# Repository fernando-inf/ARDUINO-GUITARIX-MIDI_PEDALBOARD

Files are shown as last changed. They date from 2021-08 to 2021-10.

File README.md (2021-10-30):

# FREE SOFTWARE - FREE WORLD - Try GNU / Linux is FREE.

https://www.gnu.org/

https://guitarix.org/

https://github.com/fernando-inf/ARDUINO-GUITARIX-MIDI_PEDALBOARD

# ARDUINO/GUITARIX- MIDI PEDALBOARD 
# (MIDI Input - MIDI Output)

- Licencia de uso: [GNU General Public License v3.0](https://github.com/fernando-inf/ARDUINO-GUITARIX-MIDI_PEDALBOARD/blob/main/LICENSE)
- English Version (Google translator): [ARDUINO/GUITARIX- MIDI PEDALBOARD](https://github-com.translate.goog/fernando-inf/ARDUINO-GUITARIX-MIDI_PEDALBOARD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,elem)
- Para reportar errores (Bugs) o solicitar ayuda [Registrarse en Github](https://github.com/signup?source=login) y dirijirse a la pestaña "Issues" que esta en la parte superior izquierda del repositorio.
- Para conocer a Guitarix mirar este video: [Tutorial Guitarix](https://youtu.be/nPbhc_3uhjE)

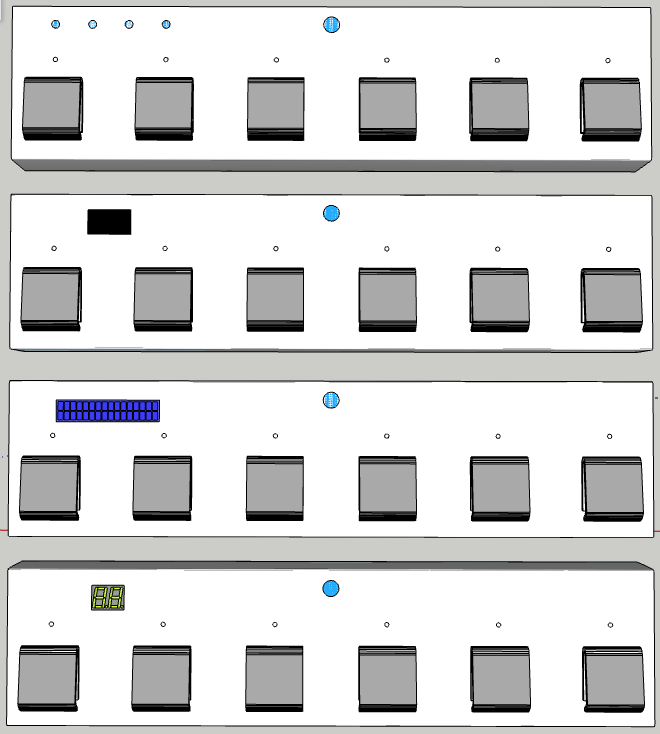
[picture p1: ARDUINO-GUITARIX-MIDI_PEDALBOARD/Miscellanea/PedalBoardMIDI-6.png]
 
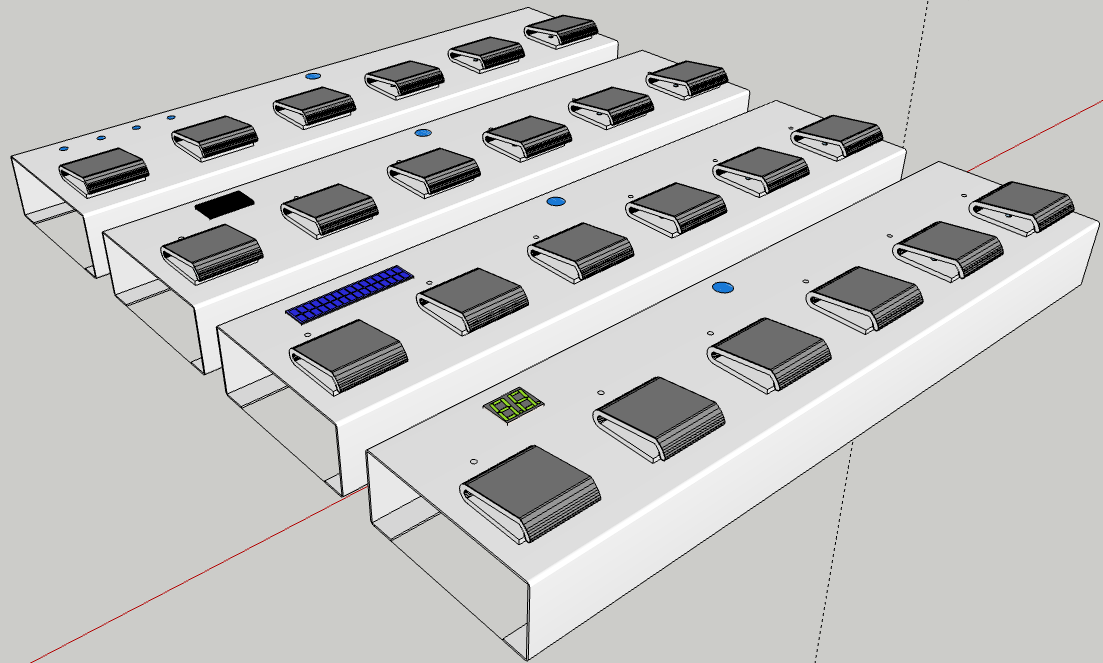
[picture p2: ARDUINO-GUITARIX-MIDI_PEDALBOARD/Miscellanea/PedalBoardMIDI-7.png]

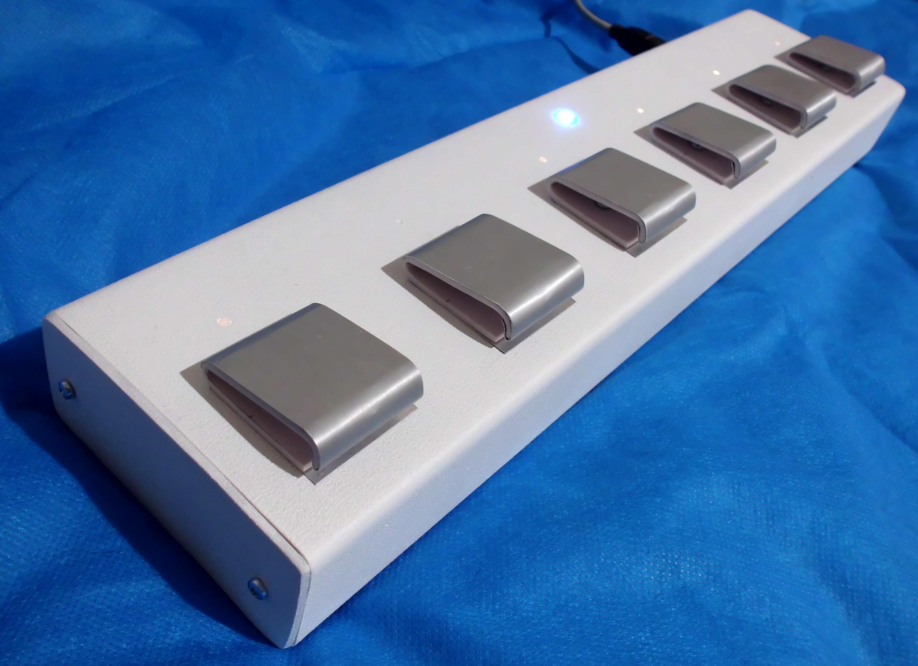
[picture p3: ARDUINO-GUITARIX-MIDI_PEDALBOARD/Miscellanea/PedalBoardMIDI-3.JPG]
 

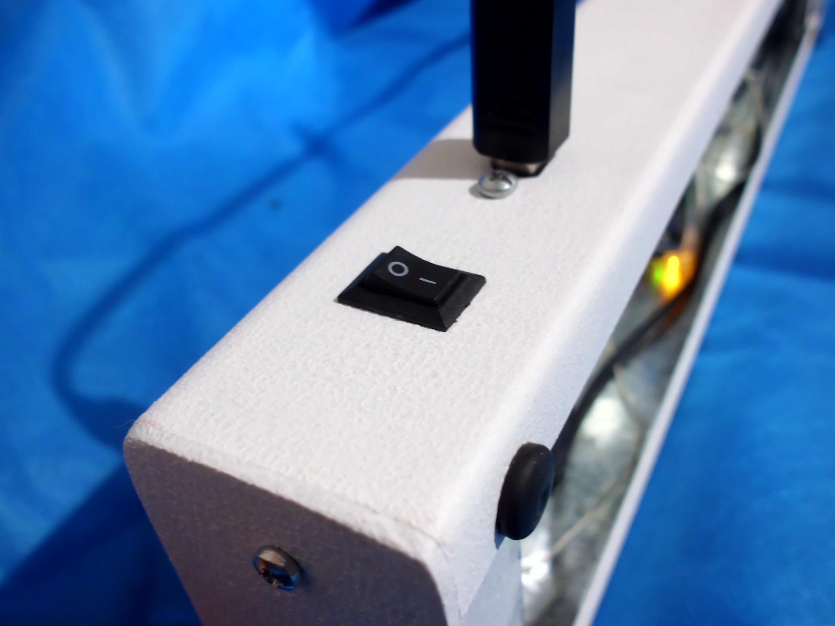
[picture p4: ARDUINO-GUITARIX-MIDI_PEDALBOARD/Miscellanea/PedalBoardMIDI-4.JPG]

 
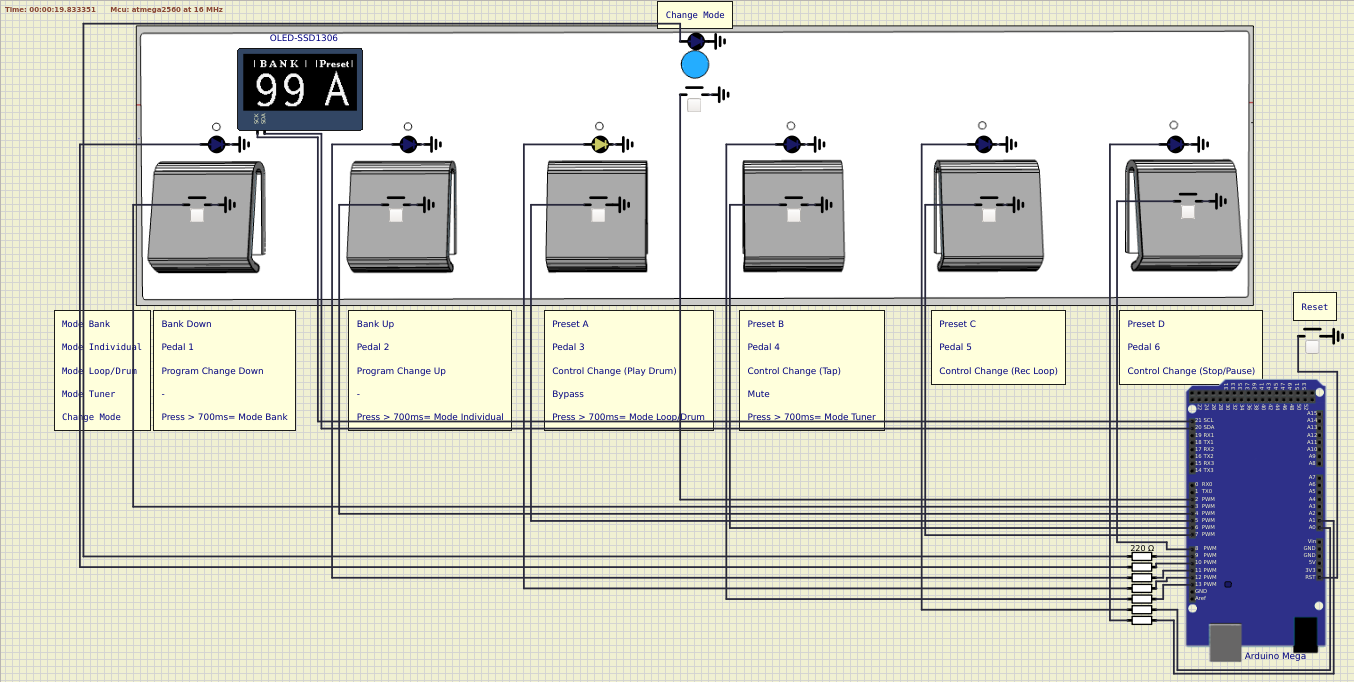
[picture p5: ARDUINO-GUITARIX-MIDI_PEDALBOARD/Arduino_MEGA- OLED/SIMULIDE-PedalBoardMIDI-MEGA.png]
 
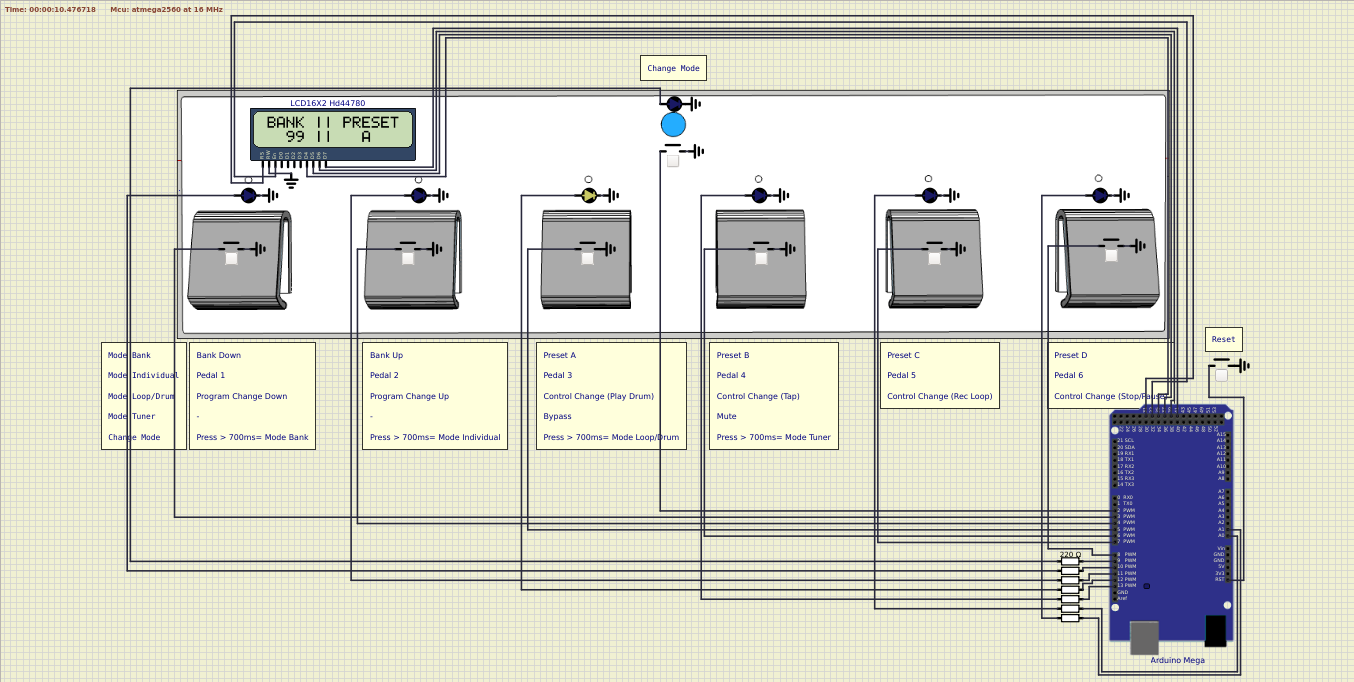
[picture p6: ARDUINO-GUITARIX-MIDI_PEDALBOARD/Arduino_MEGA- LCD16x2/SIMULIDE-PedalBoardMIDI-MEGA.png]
 
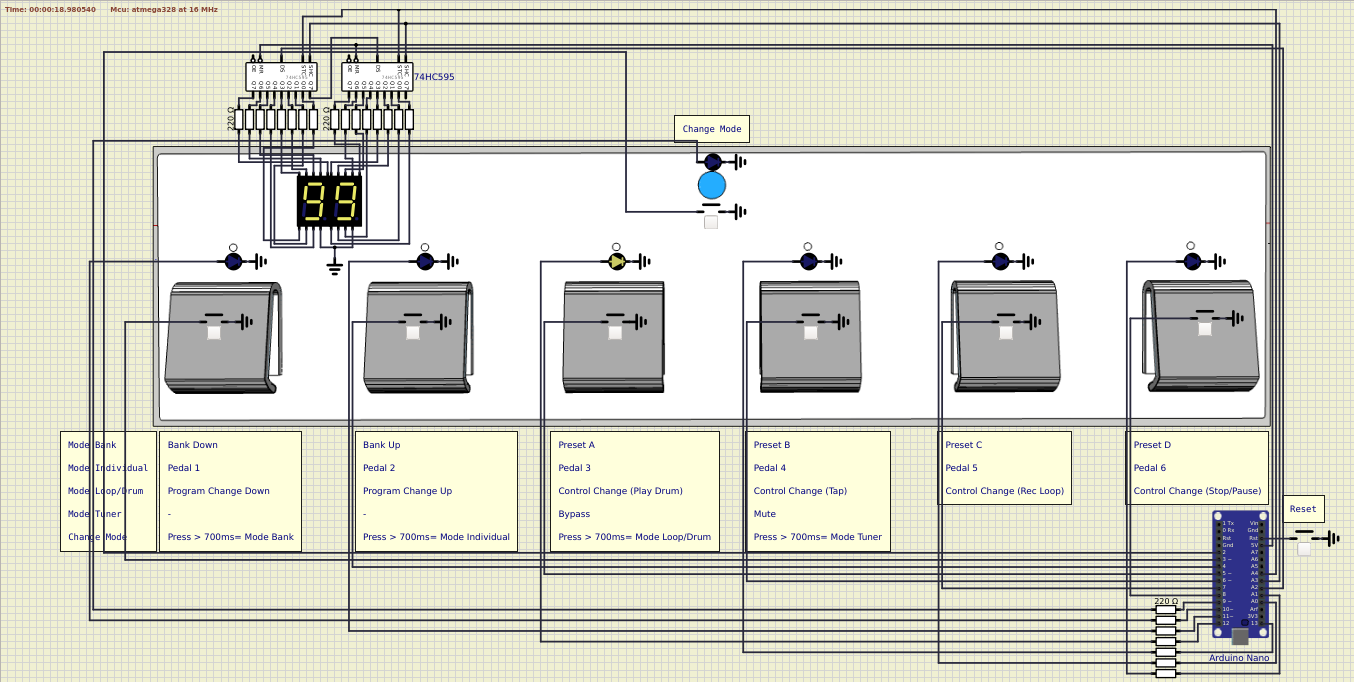
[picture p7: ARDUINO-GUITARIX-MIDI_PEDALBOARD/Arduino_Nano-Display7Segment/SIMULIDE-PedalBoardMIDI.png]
 
# INSTALACIÓN DEL FIRMWARE

- Abrir el archivo ARDUINO-GUITARIX-MIDI_PEDALBOARD.ino con Arduino IDE.

- Instále las dependencias:

  Previamente deberá tener instaladas estas librerías, para esto dirigirse a Arduino IDE "Herramientas ->   Administrar Bibliotecas..." y buscarlas:
  
  - [Bounce2](https://github.com/thomasfredericks/Bounce2)
  
  - [MIDI Library](https://github.com/FortySevenEffects/arduino_midi_library)
  
  - Si usa USB-MIDI: [Arudino USB-MIDI](https://github.com/lathoub/Arduino-USBMIDI)
  
  - Si usa Bluetooth con ESP32: 
  
      - [Pack de tarjetas adicionales ESP32](https://dl.espressif.com/dl/package_esp32_index.json)
                                
      - [Arduino BLE MIDI](https://github.com/lathoub/Arduino-BLE-MIDI)

  - Si usa LCD 16x2: [LiquidCrystal](https://www.arduino.cc/en/Reference/LiquidCrystal)
  
  - Si usa LCD 16x2 con I2C: [LiquidCrystal_I2C](https://github.com/johnrickman/LiquidCrystal_I2C)
  
  - Si usa OLED SSD1306 128x64 I2C: [U8g2](https://github.com/olikraus/u8g2)
  
- Habilíte su configuración con un valor = 1.

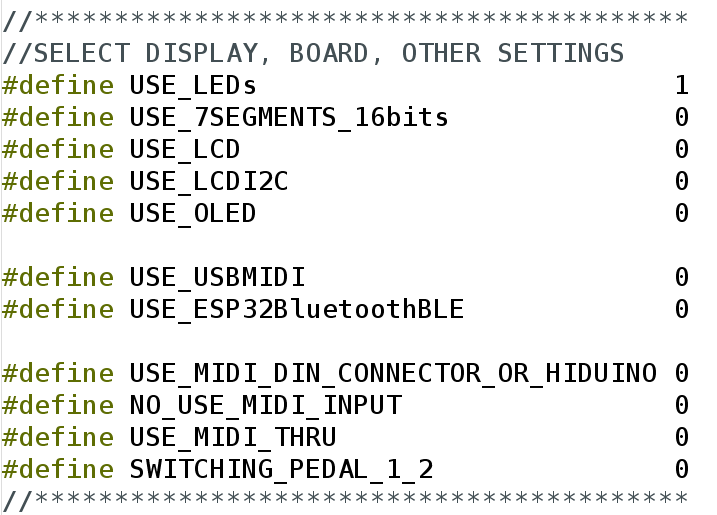
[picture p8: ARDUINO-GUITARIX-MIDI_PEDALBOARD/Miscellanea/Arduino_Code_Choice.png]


- Compilar y subir el código a su placa de desarrollo.

# SOPORTE DE PLACAS DE DESARROLLO

- Si para mostrar los datos de número de banco y preset usa:
  - LEDs: Arduino Mega, Uno, Nano, Leonardo.
  - Display 7 Segmentos 2 dígitos con chip- SIEMENS SDA2131 (16bits) o 74HC595 x 2 (8bits + 8bits): Arduino Mega, Uno, Nano, Leonardo.
  - LCD 16x2: Arduino Mega.
  - LCD 16x2 con I2C: Arduino Mega, Uno y Nano.
  - Display OLED SSD1306 I2C: Arduino Mega.
- Si usa conexión usb-midi nativa: Arduino Leonardo, Micro.
- Si usa conexión usb-midi mediante firmware Hiduino o similar: Arduino Mega 16u2, Uno 16u2.
- Si usa Bluetooth: ESP32 (Por una cuestión de limitación de pines no puede mostrar los datos de número de banco y preset)
  
# FUNCIONAMIENTO

- PULSADOR CENTRAL: El Pulsador que está en el sector medio superior del pedal y que a la misma vez contiene un LED azul cambia a MODO BANCO, INDIVIDUAL, LOOP/DRUM y TUNER.

- MODO BANCO (Canal MIDI 1): El Pedal 1 Decrementa el Valor de Banco y el Pedal 2 lo Incrementa. Los Pedales del 3 al 6 representan a un Preset A-B-C-D.

- MODO INDIVIDUAL (Canal MIDI 1): Los Pedales 1 al 6 efectúan el encendido y apagado de efectos.

- MODO LOOP/DRUM (Canal MIDI 2): El Pedal 1 y 2 suben y bajan de sample/pattern drum (usar [Hydrogen](https://github.com/hydrogen-music/hydrogen)), el Pedal 3 puede ser asignado para activar/desactivar el sample drum. El pedal 4 puede servir como TAP del programa de batería y loop, el pedal 5 para grabar el loop (usar [Sooperlooper](https://github.com/essej/sooperlooper)) y el Pedal 6 para Pause/Stop del mismo.

- MODO TUNER (Canal MIDI 1): Los LEDs de los pedales muestran el balanceo de las notas, al llegar al LED central la cuerda está afinada (esto sucede cuando el Valor de "Velocity" recibido en la Pedalera esta entre 62 y 64), las notas se muestran en el Display (solo con Display 7 segmentos, LCD u OLED). Al pasar a este Modo, se envía una señal MIDI CC 118 para encender el Afinador (usted deberá asignar este MIDI CC en el programa), al salir del Modo se envía una señal MIDI de apagado. Cuando las cuerdas no son pulsadas la Pedalera deja de mostrar datos en el Display si se recibe un MIDI CC 123. Los Pedales 3 y 4 pueden ser asignados a Bypass y Mute respectivamente.

- HOLD PEDALs: Si se mantiene presionado por más de 700ms el Pedal 1, este pasa a MODO BANCO, el Pedal 2 pasa a MODO INDIVIDUAL, el Pedal 3 pasa a MODO LOOP/DRUM, el Pedal 4 pasa a MODO TUNER.

- La Pedalera inicia en MODO BANCO en el Banco 0 y Preset 0 (A), sin embargo queda a la espera (LEDs Parpadeando) de la confirmación de selección de preset. Usted debe confirmar el preset antes de pasar el MODO INDIVIDUAL ya que, los LEDs seguirán parpadeando impidiendo el correcto funcionamiento de este MODO. Además, con cada pulsación de los Pedales 1 y 2 los LEDs volverán a Parpadear y, usted deberá necesariamente confirmar el preset.

Simulación:
Descargue la ultima versión [SimulIDE](https://www.simulide.com/p/downloads.html) que incluye soporte para Arduino.

Abrir el archivo SIMULIDE-PedalBoardMIDI.simu que se encuentra en la carpeta del proyecto. De no iniciar la simulación haga click derecho sobre la placa Arduino y LOAD FIRMWARE, luego seleccione alguno de los archivos con extensión HEX que están en la carpeta principal del proyecto.

La versión simple y económica de este proyecto esta limitada a 4 Bancos (con 4 preset cada uno, total: 16 presets), ya que son la cantidad de LEDs disponibles para mostrar el estado de los mismos en Arduino Nano. Para el uso de display se habilitan 99 bancos, con 4 presets cada uno llegando a un total de 396 presets, suficientes para un usuario común.

Esta Pedalera tiene la característica de recibir la señal MIDI del software y reflejarla en el pedal. Almacena las actualizaciones recibidas tanto en el MODO BANCO como en el MODO INIVIDUAL. Por ejemplo, si usted esta en el MODO BANCO y cambia de presets, la pedalera recibirá las actualizaciones de cada cambio de los pedales individuales (on/off) y los reflejará en los LEDs cuando usted cambie al MODO INDIVIDUAL. De esta forma sabrá el estado de los efectos sin tener que mirar la interfaz gráfica en su Monitor. Advertencia: Si selecciona en el código la opción sin MIDI INPUT, entonces al pasar del Modo Banco al Modo Individual, todos los pedales se apagarán, de esta forma el usuario estará seguro del estado de los pedales, es decir que, la función Banco e Individual no serán compatibles directamente.

# MEDIDAS

Entrar a: https://app.sketchup.com

Abrir el archivo CON EXTENSIÓN ".skp" que se encuentra en la carpeta Miscellanea.

# MATERIALES

Este proyecto pretende usar materiales reciclados, quien escribe no responde por los daños económicos que puedan causar los detalles descriptos en este apartado:

1. Arduino Nano u otra placa programable con Arduino IDE y con disponibilidad de 17 pines digitales: la conexión a la PC se hace por USB, luego usar [ttymidi](https://github.com/fernando-inf/mod-ttymidi) (en GNU/Linux es fácil de compilar) para simular un puerto MIDI (o Hairless MIDI to Serial).

2. Perfil de Chapa Galvanizada de 40,5 x 9,7 cm (Los suelen tirar en la obras de construcción): Si se lija se puede lograr hasta un brillo espejo, pero suele oxidarse fácilmente y requiere de constante mantenimiento.

3. Tubo PVC 110x2,5 mm (se corta y da la forma del pedal con calor, por ejemplo con una plancha para ropa)

4. Un retazo de madera para dar la forma interna del pedal (lijando), se usará para moldear el PVC.

5. Chapa fina (puede ser de lata de gaseosa o cerveza, lijar pintura para asegurarse de que conducirá energía) que se pegará (con Cianoacrilato – Gotita en algunos países) por encima del PVC y conducirá la señal Digital de los Pines. Esta chapa chocará con el perfil de metal (punto 2) que conducirá GND y así encenderá y apagará el Pedal. Si pinta el perfil de metal entonces tendrá que, colocar otra chapa fina por debajo del pedal de PVC que conducirá el GND para que puede tomar contacto con la señal digital.

6. 6 Leds para los pedales, 1 Led para el SwitchButton, 4 leds para mostrar la informacion del estado de los Bancos (si es que usa este opción). (para los Pedales se usaron LEDs Blancos provenientes de una Luz de Emergencia en desuso, para el resto se usaron LEDs azules de mouse óptico y Joystick de PS2)

7. Resistencias 220ohms (o mayor valor si no tiene disponibles estas), puede colocar o no estas resistencias a los LEDS (entre la salida del PIN digital de Arduino y el LED), en general es recomendable colocarlas pero, si tiene muchos LEDs para reciclar puede probar esto: si los LEDs calientan coloque resistencias, de lo contrario no serían necesarias.

8. Un pulsador de CPU que se usara para el Switch Button.

9. 12 Tornillos (con tuercas) de 3 milímetros de diámetro por 8mm de largo aprox.: se usaran para ajustar los pedales al perfil de metal, tenían un costo de AR$2 en el primer trimestre del 2021.

10. Herramientas (caladora de mano o eléctrica, taladro, lijadora, limas, etc.), lijas distintos granos y mechas para taladro de distintas medidas.

11. Alternativamente puede usar: 
    - Conector USB tipo B: reciclado de impresora o modem para no conectar directamente Arduino a la PC. 
    - Switch (on/off): reciclado de un Hub USB para encender y apagar la pedalera.
    - Porcelana fría: para dar forma al soporte de los LEDs en la parte interior del perfil de chapa galvanizada.

 

# ADVERTENCIAS/ACLARACIONES

- MIDI TRHU: Luego de hacer pruebas exhaustivas se puede decir que: Si usted en Guitarix añadió un efecto, luego le asigno un MIDI CC y luego quito este efecto: es recomendable eliminar el MIDI CC asignado en la pestaña Motor-> Controlador MIDI. Así, se determino que se evita un bucle infinito de entradas y salidas de señales MIDI (si usted no elimina el CC asignado, Guitarix continuará enviando la señal MIDI, repetidas veces) ya que el Código de este PedalBoard habilita MIDI THRU para la correcta actualización de los preset con cada cambio de los mismos. Si se envían señales repetidas de un mismo MIDI CC se produce el bucle infinito (ver: https://github.com/brummer10/guitarix/issues/80).

     - Apartir de versiones de GuitarIX [descargadas](https://github.com/brummer10/guitarix) y compiladas luego del 23/09/2021 ya no es necesario habilitar MIDI TRHU en el código: https://github.com/brummer10/guitarix/issues/85 . 

- ESP32: No se recomienda aun usar la versión Bluetooth con ESP32 ya que no es posible usar Display ni LEDs para mostrar información del estado de Bancos y Presets. 

- MIDI DIN CONNECTOR: Si usted usará conexión MIDI mediante conector MIDI DIN a un rack o pedal externo, necesitará elaborar un circuito eléctrico adicional, especialmente para la recepción de mensajes MIDI por parte de Arduino. Existen diagramas de ejemplos en la web, búsquelos.

- La Chapa fina de lata de gaseosa mencionada en la sección  "Materiales", no ha sido probada en este proyecto (se uso otra placa antigua que se tenia disponible). Se puede notar que tiene mucha flexibilidad y se parte fácilmente al doblarla completamente, sin embargo es viable probarla ya que parece ser una buena alternativa de fácil disponibilidad.

- Considere usar [Noise Repellent](https://github.com/lucianodato/noise-repellent) como Reductor de Ruido (No es puerta de Ruido), si bien provoca latencia, vale la pena probarlo.

# OTRA INFORMACIÓN

- ASIGNACIÓN DE PINES Y MIDI CC: Abra el archivo ARDUINO-GUITARIX-MIDI_PEDALBOARD.ino con Arduino IDE. En la primer pestaña encontrará los pines asignados a LEDs y Pedales. Todos los Pines y señales MIDI CC son modificables pero, no realice ningún cambio sin antes hacer una copia de los archivos. Puede usar simuladores (SimulIDE) y el Debug de Hairless MIDI to Serial para probar los cambios que realice.
Ver la simulación en SimulIDE para entender mejor la asignación de Pines:

  - `byte buttonPin[] = {2, 3, 4, 5, 6, 7, 8}; //Pines Digitales pulsadores`

  - `const byte LED[] = {9, 10, 11, 12, 13, A0, A1,A2, A3, A4, A5}; //Pines Digitales Leds`

  - `const byte CC[] = {51, 52, 53, 54, 55, 56}; //Número de Control Change (MIDI CC) para cada pedal.`
  
- TTYMIDI: Si usa ttymidi en GNU/Linux, desargue y compile desde aquí: https://github.com/fernando-inf/mod-ttymidi
Recuerde que ttymidi solo se iniciará (comando `ttymidi` en terminal) si conecto previamente Arduino al puerto usb. Así mismo verifique que previamente no ha quedado abierta otra instancia de ttymidi, de ser así, ciérrela en su Gestor/Administrador de tareas.

- HAIRLESS-MIDISERIAL: Si usa Hairless-Midiserial (en formato compilado solo está disponible para sistemas operativos de 32 bits en GNU/Linux, tendrá que instalar librerías adicionales para usarlo en sistemas de 64bits) no habilite MIDI THRU.

Tenga la gentileza de informarme sobre los avances significativos que haga usted en el proyecto y de enviarme fotos de su versión de esta pedalera.

# DONACIONES

Si considera util este aporte a la comunidad, puede realizar una donación mediante PAYPAL para continuar con el desarrollo de Software Libre:

email Paypal: fernando-inf@hotmail.com

2021 @CopyLeft

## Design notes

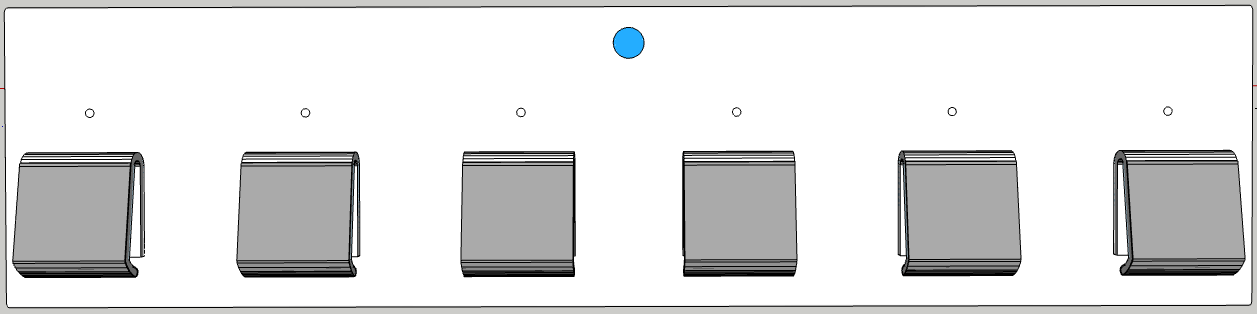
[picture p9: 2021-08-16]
ARDUINO-GUITARIX-MIDI_PEDALBOARD/Arduino_Nano-Display7Segment/PedalBoardMIDI-1.png

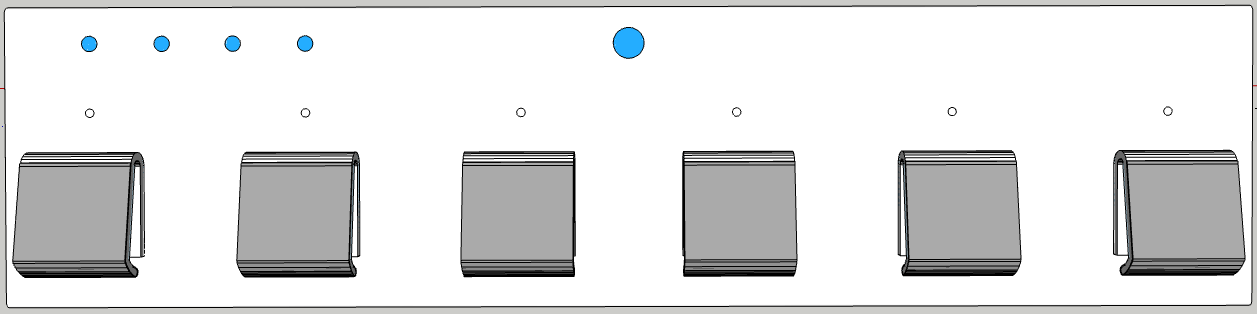
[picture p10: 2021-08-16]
ARDUINO-GUITARIX-MIDI_PEDALBOARD/Arduino_Nano-LEDs/PedalBoardMIDI-1.png

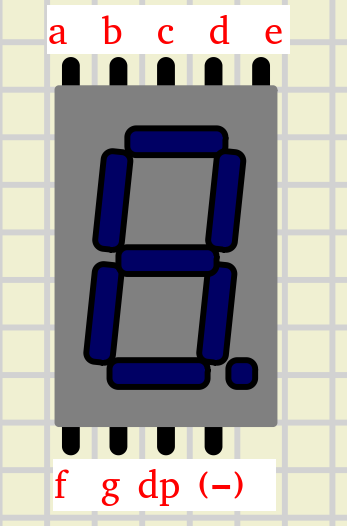
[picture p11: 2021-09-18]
ARDUINO-GUITARIX-MIDI_PEDALBOARD/Arduino_Nano-Display7Segment/DisplaySimulIDE.png

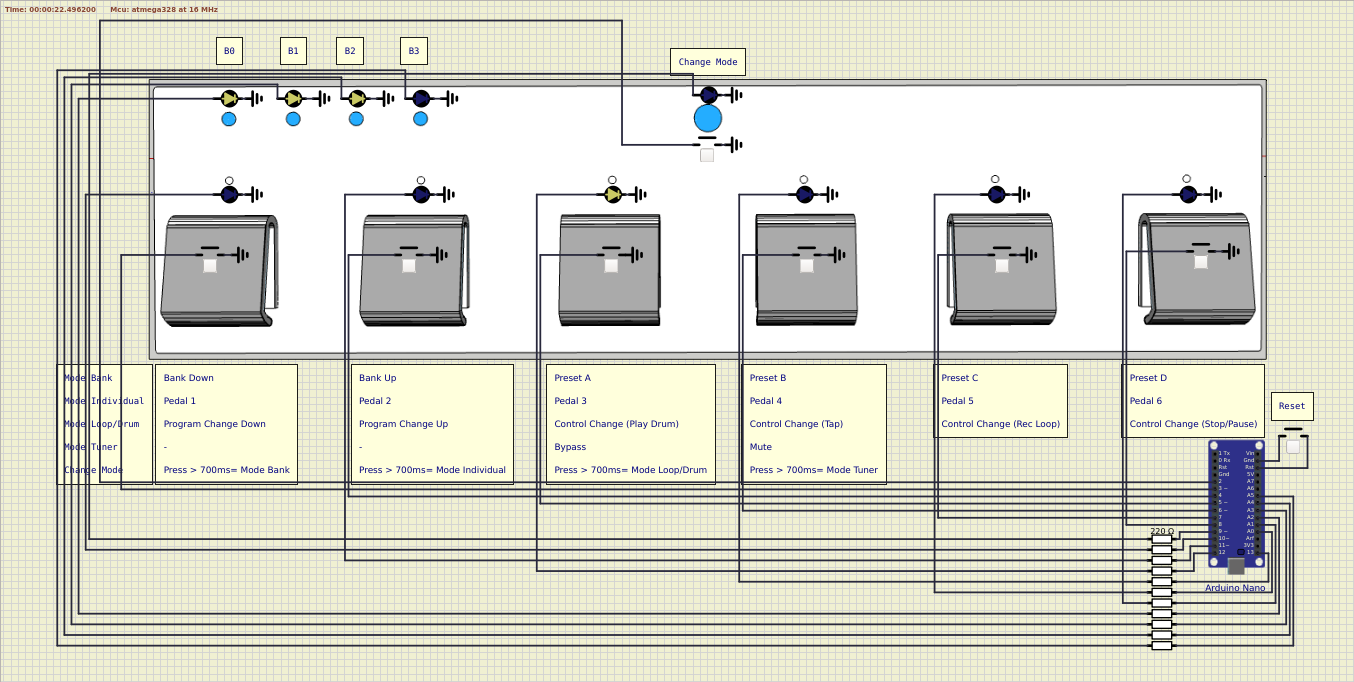
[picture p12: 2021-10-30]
ARDUINO-GUITARIX-MIDI_PEDALBOARD/Arduino_Nano-LEDs/SIMULIDE-PedalBoardMIDI.png

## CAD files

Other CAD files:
SIMPLE_MIDI_GUITARIX_PEDALBOARD/SKETCHUP-SIMPLE-MIDI-GUITARIX-PEDALBOARD.skp

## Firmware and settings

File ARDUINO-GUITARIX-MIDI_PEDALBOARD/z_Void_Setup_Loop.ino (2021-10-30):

void setup() {
  MIDI.begin(MIDI_CHANNEL_OMNI); //MIDI_CHANNEL_OMNI= Lee los mensajes de todos los Canales, si está vacío solo lee el Canal 1 en MIDI IN.
#if USE_MIDI_DIN_CONNECTOR_OR_HIDUINO
  Serial.begin(31250); // Si conecta Arduino mediante conector MIDI DIN a algún rack o pedal con Midi Input, o si usa Arduino con 16u2 y Firmware Hiduino o similar.
#elif USE_USBMIDI || USE_ESP32BluetoothBLE
#else
  Serial.begin(115200); // Si conecta Arduino por comunicación serial a la PC (Chip FTDI232 o Ch340).
#endif

#if NO_USE_MIDI_INPUT
#else
  MIDI.setHandleControlChange(MIDI_Input_CC); //MIDI Input ControlChange ver "Void MIDI_Input".
  MIDI.setHandleProgramChange(MIDI_Input_ProgramChange);  //MIDI Input ProgramChange ver "Void MIDI_Input".
  MIDI.setHandleNoteOn(Tuner);
#endif

  //*****************
#if USE_MIDI_THRU //ver: https://github.com/brummer10/guitarix/issues/80
#if USE_USBMIDI || USE_ESP32BluetoothBLE
  MIDI.turnThruOn();  //En biblioteca USB-MIDI/BLEEMIDI, MIDI-Thru está desactivado por defecto: https://github.com/lathoub/Arduino-USBMIDI
#else
#endif
#else
#if USE_USBMIDI || USE_ESP32BluetoothBLE
#else
  MIDI.turnThruOff();//Evita que la señales que entran vuelvan a salir, en librería MIDI, MIDI-Thru está activado por defecto.
#endif
#endif
  //*****************

#if USE_ESP32BluetoothBLE
  BLEMIDI.setHandleConnected(OnConnected); //Enciende LED cuando el Dispositivo se ha conectado por Bluetooth.
  BLEMIDI.setHandleDisconnected(OnDisconnected); //Apaga LED cuando el Dispositivo se ha desconectado.
  pinMode(LED_BUILTIN, OUTPUT); //PIN = GPIO2- Habilita LED indicador de conexión Bluetooth
  digitalWrite(LED_BUILTIN, LOW);
#endif

#if USE_LEDs

#if USE_ESP32BluetoothBLE
  for (byte i = 0; i < 7; i++) {
    pinMode(LED[i], OUTPUT);
  }
  for (byte i = 0; i < 7; i++) {
    digitalWrite(LED[i], LOW);
  }
#else
  for (byte i = 0; i < 11; i++) {
    pinMode(LED[i], OUTPUT);
  }
#endif

#elif USE_7SEGMENTS_16bits
  for (byte i = 0; i < 10; i++) {
    pinMode(LED[i], OUTPUT);
  }
#else
  for (byte i = 0; i < 7; i++) {
    pinMode(LED[i], OUTPUT);
  }
#endif

  //BOUNCE2 - http://thomasfredericks.github.io/Bounce2/files/functions.html
#if USE_ESP32BluetoothBLE
  for (byte x = 0; x < 6; x++) {
    pinMode(buttonPin[x], INPUT);  //Sin PULLUP INTERNO
  }
#else
  for (byte x = 0; x < 7; x++) {
    pinMode(buttonPin[x], INPUT_PULLUP);  //Con PULLUP INTERNO
  }
#endif

  switchButton_0.attach(buttonPin[0]);
  switchButton_0.interval(25);
  switchButton_0.setPressedState(LOW);

  pedal_1.attach(buttonPin[1]);
  pedal_1.interval(25);
  //pedal_1.setPressedState(LOW);

  pedal_2.attach(buttonPin[2]);
  pedal_2.interval(25);
  pedal_2.setPressedState(LOW);

  pedal_3.attach(buttonPin[3]);
  pedal_3.interval(25);
  pedal_3.setPressedState(LOW);

  pedal_4.attach(buttonPin[4]);
  pedal_4.interval(25);
  pedal_4.setPressedState(LOW);

  pedal_5.attach(buttonPin[5]);
  pedal_5.interval(25);
  pedal_5.setPressedState(LOW);

  pedal_6.attach(buttonPin[6]);
  pedal_6.interval(25);
  pedal_6.setPressedState(LOW);


#if USE_LEDs
  LED_Presets();
  delay(500);
#elif USE_7SEGMENTS_16bits
  displayNum(0, 0);
  LED_Presets();
  delay(500);
#elif USE_LCD  //LCD 16x2 sin I2C CON ARDUINO MEGA
  lcd.begin(16, 2);
  lcd.setCursor(0, 0);

  lcd.clear();
  lcd.setCursor(0, 0);
  lcd.print("      MIDI      ");
  lcd.setCursor(0, 1);
  lcd.print("   PEDALBOARD   ");

  delay(1000);
  LCD_OLED();
#elif USE_I2C_LCD
  lcd.init();
  lcd.backlight();
  lcd.noAutoscroll();

  lcd.clear();
  lcd.setCursor(0, 0);
  lcd.print("      MIDI      ");
  lcd.setCursor(0, 1);
  lcd.print("   PEDALBOARD   ");
  delay(1000);
  LCD_OLED();
#elif USE_OLED  //OLED 128x64
  u8g2.begin();

  u8g2.clearBuffer();
  u8g2.setFont(u8g2_font_ncenB10_tr);
  u8g2.setCursor(22, 20);
  u8g2.print("  | MIDI |  ");
  u8g2.sendBuffer();

  u8g2.setFont(u8g2_font_profont22_tr);
  u8g2.setCursor(5, 50);
  u8g2.print("PEDALBOARD");
  u8g2.sendBuffer();

  delay(1000);
  LCD_OLED();
#endif

  //Mensajes MIDI enviados al inicio
  MIDI.sendControlChange(0, 0, Ch);  //Inicia en Banco = 0- MIDI.sendControlChange(CCBank, valBank, ch); CC=0 es MSB, CC=32 es LSB.
  MIDI.sendProgramChange(0, Ch);     //Inicia en el Preset 0.
  //delay(100);
  //MIDI.sendControlChange(1, valOn, Ch); //Trabaja en Noise Repellent con Noise_Learn (usando mod-host en vez de Jalv). Al iniciarse la pedalera envía un CC1 con Valor ON para iniciar la lectura de ruido por 100ms (delay). Se coloca esta línea aquí para que se ejecute solo una vez al inicio.
  //delay(100);
  //MIDI.sendControlChange(1, valOff, Ch); // Luego de 100ms se apaga la toma de muestra de ruido con un Valor OFF.
}

void loop() {
#if NO_USE_MIDI_INPUT
  while (MIDI.read()) {//Los controladores MIDI que solo transmiten datos deben estar diseñados para leer e ignorar todos mensajes entrantes. Si su Software PC está enviando mensajes MIDI, este código simple evitará problemas con los búferes que se llenan con nunca leer mensajes. https://www.pjrc.com/teensy/td_midi.html
    /*read & ignore incoming messages*/
  }
#else
  MIDI.read();  //Lee los mensajes MIDI entrantes de todos los Canales, si quiere leer solo el Canal 1 = MIDI.read(1)
#endif

  switchButton();
  Pedal1();  //Llama a las funciones "void" para ser ejecutadas aquí.
  Pedal2();
  Pedal3();
  Pedal4();
  Pedal5();
  Pedal6();
  BlinkLEDPC();
  BlinkLEDLoopD();
}

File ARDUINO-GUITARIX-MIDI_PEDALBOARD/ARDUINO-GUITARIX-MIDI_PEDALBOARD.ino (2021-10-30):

/*
  ARDUINO-GUITARIX-MIDI_PEDALBOARD

  GITHUB:
  https://github.com/fernando-inf/ARDUINO-GUITARIX-MIDI_PEDALBOARD

  -----------GNU General Public License v3.0---------
  --------------fernando-inf@hotmail.com--------------
  ------------------2021 @CopyLeft--------------------

  ADVERTENCIA:
  Las opciones USE_LCD, USE_OLED y USE_7SEGMENTS_16bits (con Chip 74HC595) solo se han probado mediante simulador.
  Las opciones USE_LCDI2C, USE_USBMIDI y USE_ESP32BluetoothBLE no se han probado en simulador, ni en Hardware.
*/

//*****************************************
//SELECT DISPLAY, BOARD, OTHER SETTINGS WHIT 1.
#define USE_LEDs                          1  //Si Muestra la información con luces led = 1, de lo contrario 0. Solo Arduino Mega, Uno, Nano, Leonardo.
#define USE_7SEGMENTS_16bits              0  //Si Muestra la información con Display 7 Segmentos 2 Dígitos + SIEMENS SDA-2131 (16bits) o 2 x 74HC595 (8bits + 8bits)= 1, de lo contrario 0. Ver 74HC595 (8bits x 2): https://youtu.be/QI1IJLB42G8?t=593 . Solo Arduino Mega, Uno, Nano, Leonardo.
#define USE_LCD                           0  //Si Muestra la información con LCD = 1, de lo contrario 0. Solo Arduino Mega.
#define USE_LCDI2C                        0  //Si Muestra la información con LCD I2C = 1, de lo contrario 0. Solo Arduino Mega, Uno y Nano.
#define USE_OLED                          0  //Si Muestra la información con OLED = 1 (SSD1306 128x64 I2C), de lo contrario 0. Solo Arduino Mega.

#define USE_USBMIDI                       0  //Si usa conexión USB Nativa = 1. Solo Arduino Leonardo/Micro.
#define USE_ESP32BluetoothBLE             0  //Si usa Bluetooth con ESP32, está limitado en número de Pins, no puede mostrar el estado de los Bancos con luces LED ni LCD/OLED, a futuro se implementará uso de MUX. ¡ADVERTENCIA!: Los pulsadores no usan PULLUP interno.

#define USE_MIDI_DIN_CONNECTOR_OR_HIDUINO 0  //Si conecta Arduino mediante conector MIDI DIN a algún rack o pedal con Midi Input, o si usa Arduino con 16u2 y Firmware Hiduino o similar = 1, de lo contrario 0.
#define NO_USE_MIDI_INPUT                 0  //Si su PC o equipo (Rack, Pedal... ) no enviará señales MIDI a Arduino = 1, de lo contrario 0.
#define USE_MIDI_THRU                     0  //Si quiere que las señales MIDI Input vuelvan a salir por MIDI Output = 1, de lo contrario 0. En Guitarix es necesario (para versiones descargadas y compiladas hasta antes del 22/09/2021 https://github.com/brummer10/guitarix/issues/85 ) MIDI Thru para resolver este conflicto: https://github.com/brummer10/guitarix/issues/80 . Advertencia: En ocasiones puede provocar un bucle infinito de entradas y salidas de señales MIDI.
#define SWITCHING_PEDAL_1_2               0  //Si entre el PEDAL 1 o 2 solo quiere mantener uno encendido = 1, de lo contrario = 0. Sirve para casos en que ambos pedales tengan asignado un efecto con distorsión y solo se quiera mantener uno solo encendido.
//*****************************************

#include <Bounce2.h>  //https://github.com/thomasfredericks/Bounce2

#if USE_USBMIDI
#include <USB-MIDI.h>  //https://github.com/lathoub/Arduino-USBMIDI
USBMIDI_CREATE_DEFAULT_INSTANCE();

#elif USE_ESP32BluetoothBLE  //https://github.com/lathoub/Arduino-BLE-MIDI
#include <BLEMIDI_Transport.h>
#include <hardware/BLEMIDI_ESP32.h>  //Tambien puede probar usando NimBLE, en cuyo caso deshabilite esta línea y la próxima
BLEMIDI_CREATE_DEFAULT_INSTANCE()
//#include <hardware/BLEMIDI_ESP32_NimBLE.h>//Habilite esta línea si usa NimBLE.
//BLEMIDI_CREATE_INSTANCE("CustomName", MIDI)//Habilite esta línea si usa NimBLE.
void OnConnected() {  //Enciende LED cuando el Dispositivo se ha conectado por Bluetooth.
  digitalWrite(27, HIGH);
}
void OnDisconnected() { //Apaga LED cuando el Dispositivo se ha desconectado.
  digitalWrite(27, LOW);
}

#else
#include <MIDI.h> //https://github.com/FortySevenEffects/arduino_midi_library
MIDI_CREATE_DEFAULT_INSTANCE();
#endif


#if USE_ESP32BluetoothBLE
byte buttonPin[] = { 32, 33, 34, 35, 36, 39 }; //Pines Digitales ¡SIN PULLUP INTERNO! en ES32 para: Pedal0, Pedal1, Pedal2,... , Pedal6
#else
byte buttonPin[] = { 2, 3, 4, 5, 6, 7, 8 }; //Pines Digitales para: switchButton_0/Pedal0, Pedal1, Pedal2,... , Pedal6
#endif
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

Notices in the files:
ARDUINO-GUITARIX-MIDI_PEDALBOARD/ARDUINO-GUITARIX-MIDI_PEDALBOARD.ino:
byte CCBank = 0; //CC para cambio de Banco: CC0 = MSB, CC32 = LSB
